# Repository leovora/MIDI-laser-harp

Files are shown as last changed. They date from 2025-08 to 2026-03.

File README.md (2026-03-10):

# MIDI Laser Harp






> **University Project** — Making Lab Course, A.Y. 2024/2025 <br>
> Alma Mater Studiorum — Università di Bologna <br>
> Author: [Leonardo Vorabbi](https://github.com/leovora)

---

This project was developed as part of the **Making Lab** course exam (Academic Year 2024/2025) at the **Master's Degree in Computer Science, University of Bologna**.

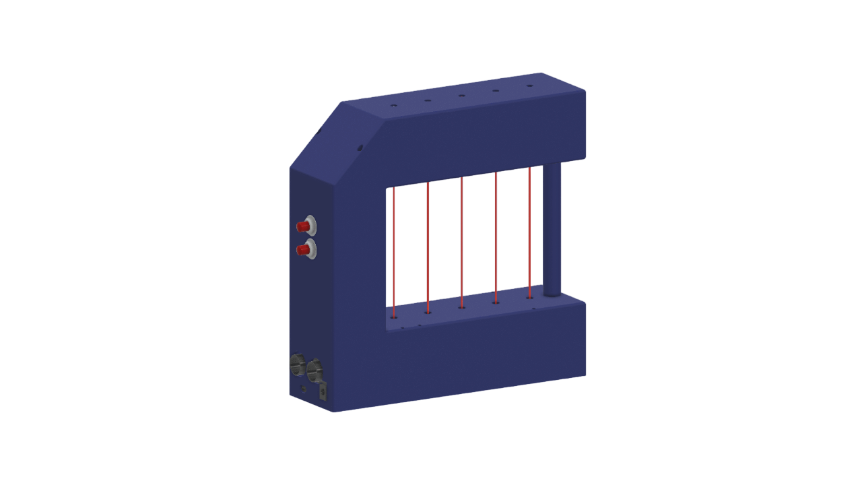
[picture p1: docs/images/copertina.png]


## Project Description
The goal of my project was to design and build a **laser harp MIDI controller**, capable of interacting with music software (such as Ableton, Logic, or other DAWs) through MIDI messages.

The system works by projecting laser beams onto LDR sensors: interrupting a beam is interpreted as triggering or releasing a note (Note On/Off).

In addition to the core functionality, the following features were integrated:
- **Feedback LEDs**, to provide visual feedback to the user;
- **Ultrasonic sensor**, for continuous control of MIDI parameters (e.g. effects or modulation);
- **Octave shift buttons**, to extend the musical range of the instrument;
- a **configuration software** able to send and receive *Control Change* messages for note remapping and device status monitoring.

## CAD Model
The physical structure of the instrument was designed in **Autodesk Fusion 360** and built using **FDM 3D printing**.

Exploded model

## Technologies Used
- **Arduino + MIDIUSB** for MIDI message handling
- **NewPing** for the ultrasonic sensor
- **Autodesk Fusion 360** for CAD modeling
- **Ultimaker Cura** and **Ultimaker 3** for 3D printing
- **Ableton Live** as the reference DAW for testing

## Repository Structure
- `src/` → Arduino code (for the device) and Python code (for the configuration software)
- `stl/` → 3D models in STL format
- `docs/` → images and additional documentation

## Author
Project developed by **Leonardo Vorabbi**  
University of Bologna – Master's Degree in Computer Science  
Making Lab, A.Y. 2024/2025

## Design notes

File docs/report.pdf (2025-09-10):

## Report progetto Laboratorio di Making Universit`a di Bologna

A.A. 2024-25

## MIDI Laser-Harp

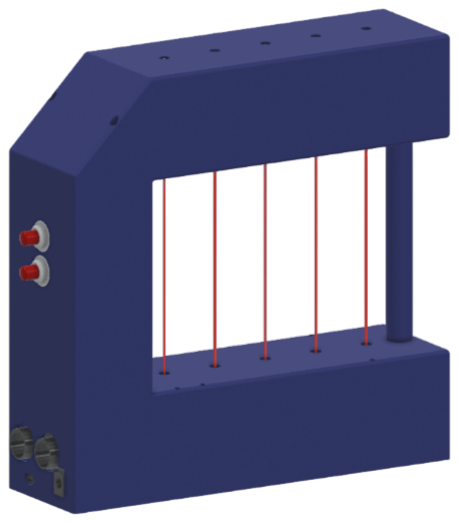
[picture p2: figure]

### Leonardo Vorabbi

0001186597

### Email

leonardo.vorabbi@studio.unibo.it

## Indice

1 Introduzione | 2
2 Stato dell’arte | 3
3 Materiali e componenti utilizzati | 5
4 Progettazione | 6
4.1.2 | Codice Arduino per calibrazione e lettura dei sensori . | 7
4.3.1 | Trasferimento del circuito dalla breadboard a stripboard 10
5 Conclusioni | 15
6 Appendice | 16

1

## 1 Introduzione

### 1.1 Contesto del progetto

Negli ultimi anni il campo degli strumenti musicali elettronici ha conosciuto una rapida evoluzione, grazie alla diffusione di controller MIDI sempre pi`u vari e innovativi. Accanto a tastiere, pad e superfici di controllo tradizionali, sono comparsi strumenti alternativi che sfruttano diverse tecnologie per offrire modalit`a di interazione pi`u intuitive ed espressive.

Tra i marchi pi`u innovativi nel settore dei controller MIDI spicca ROLI, che ha introdotto soluzioni capaci di ampliare notevolmente le possibilit`a espressive del musicista. Con la serie Seaboard, ROLI ha portato sul mercato superfici sensibili alla pressione e al movimento, basate sul protocollo MPE (MIDI Polyphonic Expression), che consentono di modulare parametri sonori in tempo reale con un approccio molto pi`u fluido rispetto alle tastiere tradizionali. A queste si affiancano dispositivi come l’Airwave, che sfruttano la visione artificiale per interpretare i gesti del performer e tradurli in controlli musicali, aprendo la strada a un’interazione pi`u naturale e gestuale con il suono.

In questo panorama si colloca il progetto MIDI Laser-Harp, che si ispira alle celebri arpe laser utilizzate in ambito performativo da artisti come Jean-Michel Jarre, ma con un approccio pi`u accessibile e compatto. L’obiettivo `e creare un dispositivo che permetta all’esecutore di interagire gestualmente con fasci di luce, traducendo l’interruzione dei laser in segnali MIDI compatibili con software musicali e sintetizzatori.

Il progetto si inserisce quindi nel filone della ricerca di nuove interfacce uomo–macchina per la musica elettronica, ponendo l’accento sull’aspetto performativo e sulla libert`a gestuale.

### 1.2 Controller e protocollo MIDI

Un controller musicale non produce suoni autonomamente, ma invia comandi a un generatore sonoro esterno, che pu`o essere un sintetizzatore hardware o un software di produzione musicale. Questi comandi sono trasmessi tramite il protocollo MIDI (Musical Instrument Digital Interface), uno standard introdotto negli anni ’80 che consente a strumenti e computer di comunicare tra loro. Il MIDI non trasporta il suono, ma una serie di istruzioni digitali, come “nota ON/nota OFF”, che vengono interpretate dal dispositivo ricevente per generare o modulare il suono. In questo modo, un controller come

2

l’arpa laser pu`o diventare un’interfaccia che permette al musicista di suonare virtualmente strumenti molto diversi tra loro e delegando la sintesi del suono al dispositivo/software ricevente.

### 1.3 Obiettivo del progetto

Obiettivo del progetto `e la realizzazione di un’arpa laser MIDI. L’intento `e sviluppare uno strumento musicale alternativo capace di trasformare l’interruzione di fasci laser in segnali MIDI standard, in modo da poter interagire facilmente con software di produzione musicale e sintetizzatori hardware. La progettazione include non solo l’elettronica di rilevamento e comunicazione, ma anche la creazione di un contenitore stampato in 3D che integri in maniera ordinata laser, sensori e scheda di controllo. L’obiettivo finale `e fornire un dispositivo completo che possa fungere da base per future estensioni.

## 2 Stato dell’arte

### 2.1 Prodotti esistenti

A seguito di una ricerca online, ho individuato un solo prodotto attualmente in vendita che possa essere definito a tutti gli effetti un’arpa laser: si tratta del modello proposto su laser-harp.com, commercializzato a 999 €. Questo strumento, tuttavia, si discosta molto dal progetto qui presentato: `e concepito principalmente come dispositivo scenografico, pensato per spettacoli e performance dal forte impatto visivo, ma con funzionalit`a musicali piuttosto limitate e un costo che lo rende poco accessibile.

In parallelo esistono altri controller MIDI alternativi basati su sensori di movimento o di prossimit`a. Tra questi, ad esempio, il Leap Motion e l’Airwave di ROLI (basati su sensori ottici capaci di rilevare con precisione i gesti delle mani nello spazio). E importante sottolineare per`o che questi dispositivi sono ` accomunati all’arpa laser soltanto dall’obiettivo di rendere l’interazione con il suono pi`u naturale e immediata rispetto a tastiere o controller tradizionali, offrendo tuttavia interfacce gestuali diverse.

### 2.2 Analisi progetti online

Online sono disponibili diversi progetti di arpe laser, come ad esempio https: //www.instructables.com/Laser-Harp-2/. La maggior parte di essi si basa su un unico laser di potenza relativamente elevata (> 50 mW), il cui fascio

3

viene deviato da uno specchio montato su un motore passo-passo che ruota ad alta velocit`a. In questo modo si ottiene l’illusione di avere pi`u raggi paralleli, corrispondenti a corde virtuali. Un LDR misura la luminosit`a e l’eventuale interruzione del fascio viene associata a una determinata nota, in base alla posizione del motore durante l’interruzione. Questo approccio, seppur scenografico, presenta diversi limiti: il costo del laser, la scarsa portabilit`a, il rischio per gli occhi dovuto all’uso di raggi potenti e la riduzione del controllo musicale a un semplice on/off per nota.

Il progetto sviluppato adotta invece una logica differente: utilizza pi`u laser indipendenti a bassa potenza ciascuno allineato con un proprio LDR dedicato. Questa soluzione risulta meno spettacolare dal punto di vista scenico, ma molto pi`u funzionale e sicura, perch´e permette la realizzazione di un frame stampato in 3D in cui possono essere integrati altri sensori e controlli aggiuntivi, rendendo il sistema pi`u versatile. Tra i limiti rimangono la necessit`a di un allineamento preciso tra laser e sensori e una resa visiva meno scenica rispetto alle soluzioni con fasci riflessi.

4

## 3 Materiali e componenti utilizzati

### 3.1 Tabella dei componenti elettronici

Categoria | Componente | Quantit`a | Note
Scheda di controllo | Arduino Leonardo (+ protoboard) | 1 | Compatibile con MIDI via USB grazie a AT-mega32u4
Laser | HiLetgo 5 mW 650 nm Red DOT Laser Mo-dule (KY-008) | 5 | Moduli laser 5 V, luce rossa, 650 nm
Sensori ottici | LDR | 5 | Per rilevare l’interru-zione del fascio laser
Resistenze | 220 Ω | 10 | 5 per le LDR, 5 per i LED
LED | LED 5 mm | 5 | Indicatori visivi per ogni “corda”
Sensori addizionali | Sensore a ultrasuoni | 1 | Per rilevare la distan-za delle mani
Pulsanti | Pulsanti standard | 2 | Per cambio ottava
PCB | Schede perforate | 2 | Per assemblaggio e saldatura
Cablaggio | Jumper | vari

Tabella 1: Componenti elettronici principali

5

### 3.2 Tabella dei componenti di supporto

Categoria | Componente | Quantit`a | Note
Assemblaggio | Viti M3 autofilettanti | varie | Per fissaggio delle par-ti stampate in PLA
Strumenti di supporto | “Terza mano” con pinze | 1 | Per facilitare le salda-ture
Materiali stampa 3D | Filamento PLA | variabile | Per la realizzazione del ”frame”
Stampante 3D | Ultimaker 3 | 1 | Stampa del ”frame”
Software CAD/CAM | Fusion 360, Ultimaker Cura | — | Modellazione e slicing per stampa 3D

Tabella 2: Componenti di supporto e strumenti

## 4 Progettazione

### 4.1 Prototipazione su breadboard

### 4.1.1 Schema del circuito preliminare

Per la fase di prototipazione `e stato realizzato un primo circuito di test su breadboard con lo scopo di verificare il corretto funzionamento del principio di base: l’interruzione di un fascio laser rilevata da un fotoresistore (LDR) viene tradotta in un segnale digitale visibile tramite l’accensione di un LED.

Nel prototipo sono stati utilizzati:

- Due moduli laser (650 nm, 5 mW), collegati direttamente all’alimentazione a 5V fornita da Arduino Leonardo.
- Due LDR, ognuno in partitore resistivo con una resistenza da 220 Ω. Il punto centrale del partitore veniva letto da un ingresso analogico di Arduino per rilevare la variazione di luminosit`a.
- Due LED da 5 mm, ciascuno con una resistenza da 220 Ω in serie, collegati alle uscite digitali di Arduino. I LED fungevano da indicatori visivi dello “stato della corda”: spenti quando il fascio era attivo e accesi quando il fascio veniva interrotto.

6

- Due pulsanti momentanei, inizialmente collegati agli ingressi digitali di Arduino. La loro funzione era ancora in fase di definizione, ma sarebbero poi stati utilizzati per il controllo dell’ottava tramite messaggi MIDI.
- Un sensore a ultrasuoni, aggiunto per future sperimentazioni: lo scopo era valutare la possibilit`a di utilizzarlo come ulteriore parametro di controllo MIDI (per esempio, modulare un effetto in base alla distanza della mano).

Il prototipo realizzato [figura 4] ha permesso di testare la sensibilit`a degli LDR rispetto ai moduli laser e di iniziare a scrivere il codice per la calibrazione degli LDR e la trasmissione dei vari segnali MIDI.

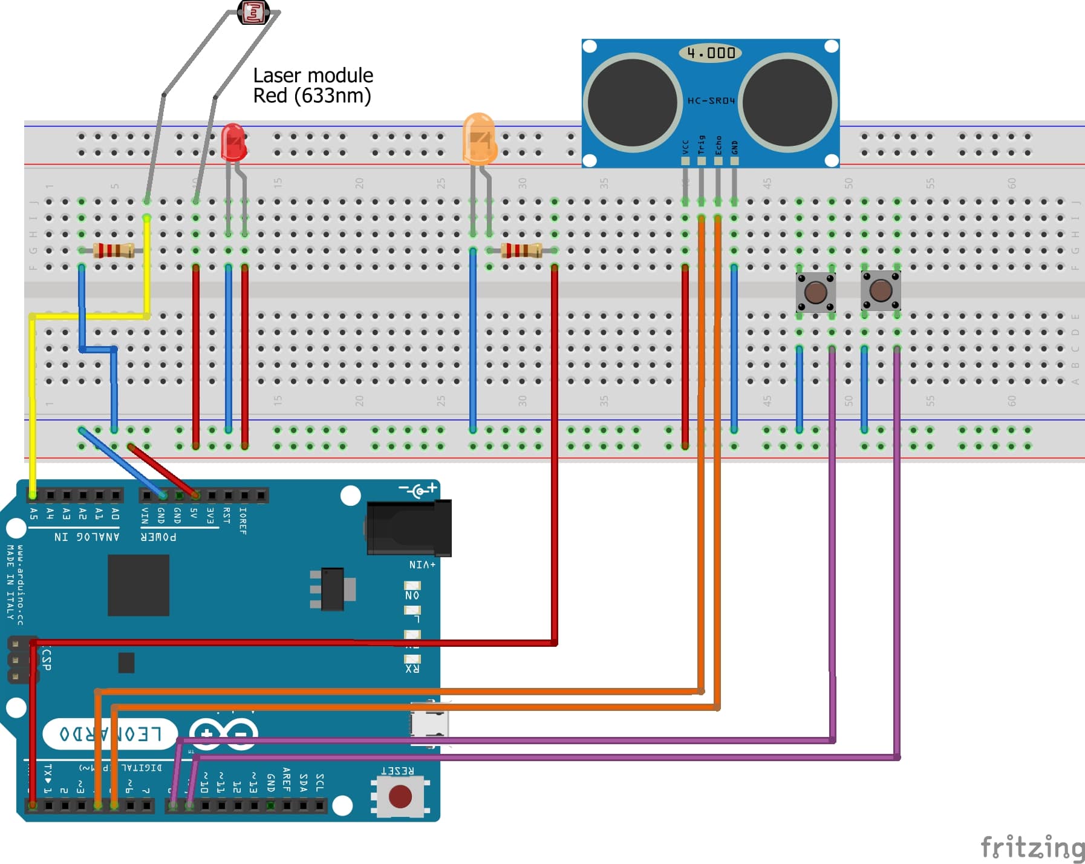
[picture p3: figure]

Figura 1: Schema circuito considerando un solo fascio laser

### 4.1.2 Codice Arduino per calibrazione e lettura dei sensori

Al fine di ridurre al minimo l’impatto della luce ambientale, variabile a seconda del contesto di utilizzo, sulla lettura dei sensori, `e stata implementata

7

una procedura di calibrazione automatica dei singoli LDR. Durante la fase di setup, ciascun sensore viene campionato per 100 letture consecutive mentre il relativo fascio laser `e attivo. La media di questi valori viene utilizzata per calcolare una soglia dinamica (threshold), leggermente inferiore alla luminosit`a rilevata in condizioni normali. In questo modo il sistema `e in grado di adattarsi alle variazioni di luce ambientale e ridurre gli errori di lettura. Nel ciclo principale, i valori analogici provenienti dagli LDR vengono confrontati con la soglia calcolata. Quando il valore scende al di sotto della soglia, significa che il fascio `e stato interrotto, e il sistema attiva la nota corrispondente, mentre quando il valore torna al di sopra della soglia, la nota viene spenta. Questo meccanismo consente di rilevare in tempo reale l’interruzione dei fasci laser e di associare ogni “corda” luminosa a una specifica nota MIDI. L’aggiunta di LED di feedback collegati a ciascun sensore permette inoltre di verificare visivamente l’attivazione e il rilascio delle note durante i test su breadboard.

Sebbene nel prototipo fossero gi`a presenti i due pulsanti e il sensore a ultrasuoni, in questa fase preliminare il codice si `e concentrato esclusivamente sulla calibrazione e sulla lettura degli LDR, rimandando l’implementazione delle funzionalit`a avanzate alla fase successiva.

Il codice completo `e disponibile al link github del progetto oppure cliccando qui.

### 4.2 Comunicazione MIDI

### 4.2.1 Codice Arduino per comunicazione MIDI

Per permettere all’arpa laser di interagire con software musicali e strumenti esterni, `e stata implementata la comunicazione MIDI tramite la libreria MIDIUSB di Arduino. Il MIDI (Musical Instrument Digital Interface) `e un protocollo digitale standardizzato che non trasmette audio, ma messaggi di controllo: istruzioni come “Nota On”, “Nota Off”, “Control Change” o “Program Change” che descrivono come uno strumento deve generare o modificare un suono.

Ogni messaggio MIDI tradizionale `e composto da tre byte:

1. Status byte: indica il tipo di messaggio e il canale MIDI (1–16).
2. Data byte 1: numero della nota o ID del controller.
3. Data byte 2: velocit`a della nota o valore del controller (0–127).

8

Quando si utilizza la libreria MIDIUSB, questi tre byte vengono incapsulati in un pacchetto USB-MIDI a quattro byte (midiEventPacket t), dove il primo byte (cin) indica al computer il tipo di messaggio USB-MIDI, mentre i successivi tre byte corrispondono ai classici messaggi MIDI.

La gestione avviene secondo due funzioni principali:

- Nota ON: quando il valore letto dall’LDR scende sotto la soglia di calibrazione, Arduino invia un messaggio Note On contenente il numero della nota corrispondente e la velocit`a massima (127). Contestualmente, viene inviato anche un messaggio di Control Change: questo non influisce sulla riproduzione musicale, ma viene utilizzato dal programma di configurazione dello strumento per aggiornare la grafica e monitorare lo stato dei sensori.
- Nota OFF: quando il valore torna sopra la soglia, Arduino invia il messaggio Note Off per la stessa nota, indicando cos`ı al software MIDI che il tasto virtuale `e stato rilasciato. Anche in questo caso viene inviato un Control Change per aggiornare il monitoraggio visivo nell’interfaccia di configurazione.

L’elenco delle note assegnate agli LDR `e gestito tramite un array (noteBase[]), che definisce la nota di riferimento per ciascun sensore. A questa nota di base pu`o essere applicato uno shift di ottava (positivo o negativo), determinato dai pulsanti presenti sul prototipo.

Sensore Nota MIDI Nota musicale
LDR1 | 60 | Do4
LDR2 | 62 | Re4
LDR3 | 64 | Mi4
LDR4 | 65 | Fa4
LDR5 | 67 | Sol4

Tabella 3: Note associate a ciascun LDR (Scala Do maggiore - prime 5 note)

Oltre ai messaggi di nota, il codice `e predisposto anche per l’invio di Control Change (CC), che permettono di mappare altri parametri musicali, come ad esempio il controllo di effetti.

Il codice completo `e disponibile al link github del progetto oppure cliccando qui.

9

### 4.2.2 Test con Ableton

Per testare il funzionamento musicale del prototipo, `e stato utilizzato Ableton Live, una delle principali Digital Audio Workstation (DAW) che permette di registrare, riprodurre e modificare musica digitale, gestendo tracce audio e MIDI.

I primi test si sono rivelati relativamente semplici: `e bastato collegare il prototipo al PC tramite USB, aprire Ableton, creare una traccia MIDI, selezionare uno strumento virtuale e attivarlo. Una volta fatto ci`o, ogni interruzione di fascio laser corrispondeva all’invio di un messaggio Note On/Off, e il suono selezionato veniva riprodotto in tempo reale.

Per testare il controllo aggiuntivo fornito dal sensore a ultrasuoni, `e stato sufficiente entrare in modalit`a MIDI Map di Ableton e selezionare il parametro desiderato da controllare (ad esempio il volume o un effetto di riverbero) associandolo al messaggio di Control Change inviato dal sensore. In questo modo il movimento della mano davanti al sensore modulava in tempo reale il parametro selezionato.

### 4.3 Assemblaggio e saldatura

### 4.3.1 Trasferimento del circuito dalla breadboard a stripboard

Dopo la fase di prototipazione su breadboard, `e stato necessario realizzare un circuito pi`u stabile e compatto, trasferendo il tutto su stripboard.

In particolare, sono stati saldati sulla stripboard il circuito dei fotoresistori e i relativi LED con resistenze, ovvero la sezione del circuito dedicata alla rilevazione delle interruzioni dei fasci laser e al feedback visivo, garantendo una maggiore robustezza.

Successivamente `e stato saldato anche il sensore a ultrasuoni direttamente sulla protoboard di Arduino, insieme ad alcuni jumper necessari a facilitare i collegamenti con il resto del sistema.

Gli altri componenti (moduli laser, pulsanti, ecc.) non sono stati integrati direttamente sulla stripboard, ma fissati in altri modi sfruttando la struttura stampata in 3D.

Per completare l’intero circuito `e stato inoltre necessario saldare numerosi cavi, al fine di unire tra loro le varie parti distribuite nel dispositivo.

10

### 4.4 Progettazione e modellazione 3D

### 4.4.1 Preparazione e misurazione

La progettazione della struttura dell’arpa laser `e partita da un abbozzo a matita, utile per definire la disposizione generale dei componenti [figura 5]. Nello schema iniziale, l’Arduino Leonardo con il sensore a ultrasuoni era collocato in basso a sinistra, mentre i moduli laser occupavano la parte centrale e destra della base. La colonna verticale a sinistra era pensata come passaggio per il cablaggio verso la parte superiore, oltre che come alloggiamento dei pulsanti per il cambio di ottava. Nella parte superiore trovavano posto gli LDR e i LED: i primi rivolti verso il basso, in modo da allinearsi con i fasci laser, e i secondi orientati verso l’alto, per essere ben visibili all’utente.

Dopo aver definito questa disposizione, `e stato necessario misurare accuratamente tutti i componenti elettronici per poterli riprodurre fedelmente in CAD e garantire un corretto alloggiamento.

### 4.4.2 Disegno CAD e stampa FDM

La modellazione `e stata svolta con Autodesk Fusion 360 e ha rappresentato una delle fasi pi`u impegnative del progetto, trattandosi della mia prima esperienza in modellazione 3D. E stato necessario non solo progettare i singoli ` pezzi, ma anche pensare a come renderli assemblabili e solidi, introducendo alloggiamenti e fori per le viti di fissaggio. Tutti i file STL prodotti sono disponibili nel repository GitHub: github.com/leovora/MIDI-laser-harp.

11

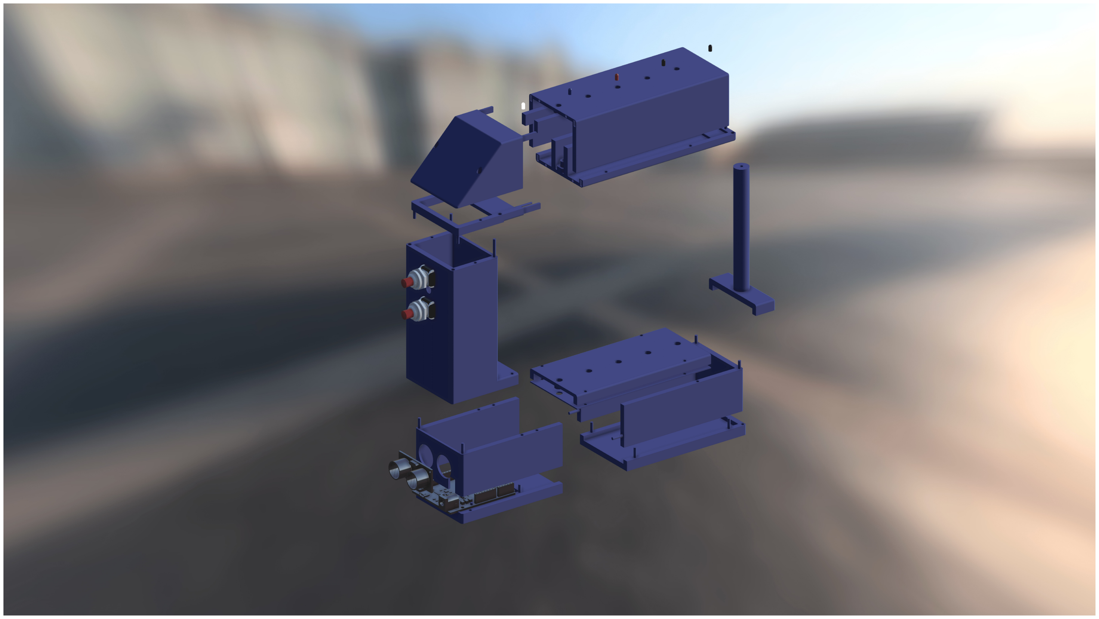
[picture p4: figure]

Figura 2: Mockup esploso con risalto sui singoli pezzi

La stampa `e stata effettuata con tecnologia FDM utilizzando Ultimaker Cura per il slicing e una Ultimaker 3 (ricevuta in prestito per un periodo limitato) per la realizzazione fisica dei componenti. Il processo `e stato di natura fortemente iterativa: modellavo un pezzo, lo stampavo, e durante la stampa lavoravo al modello successivo. In diversi casi `e stato necessario ristampare alcune parti dopo aver corretto errori di progettazione o piccole imprecisioni.

### 4.5 Assemblaggio finale

### 4.5.1 Difficolt`a riscontrate

La fase di assemblaggio `e stata senza dubbio quella in cui sono emerse le maggiori difficolt`a, poich´e solo mettendo insieme tutte le parti stampate e i componenti elettronici `e stato possibile verificare concretamente eventuali errori progettuali.

Il primo problema rilevante `e stato legato al cablaggio. Inizialmente avevo saldato ad ogni componente i propri collegamenti di alimentazione (5 V e GND), arrivando cos`ı a dover connettere oltre 30 cavi direttamente ad Arduino. Oltre alla complessit`a del cablaggio, il vero ostacolo era rappresentato dal fatto che tutti questi fili faticavano a passare all’interno della colonna sinistra. Per risolvere il problema ho dovuto tagliare e saldare molti cavi tra

12

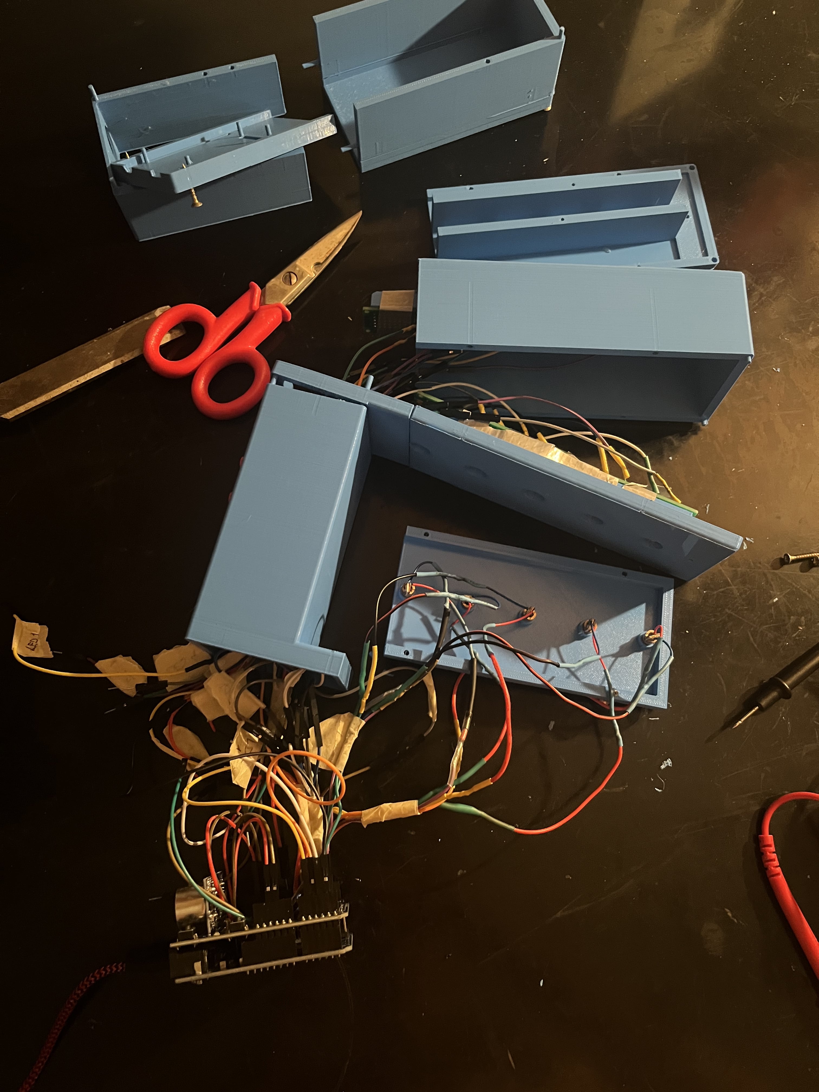
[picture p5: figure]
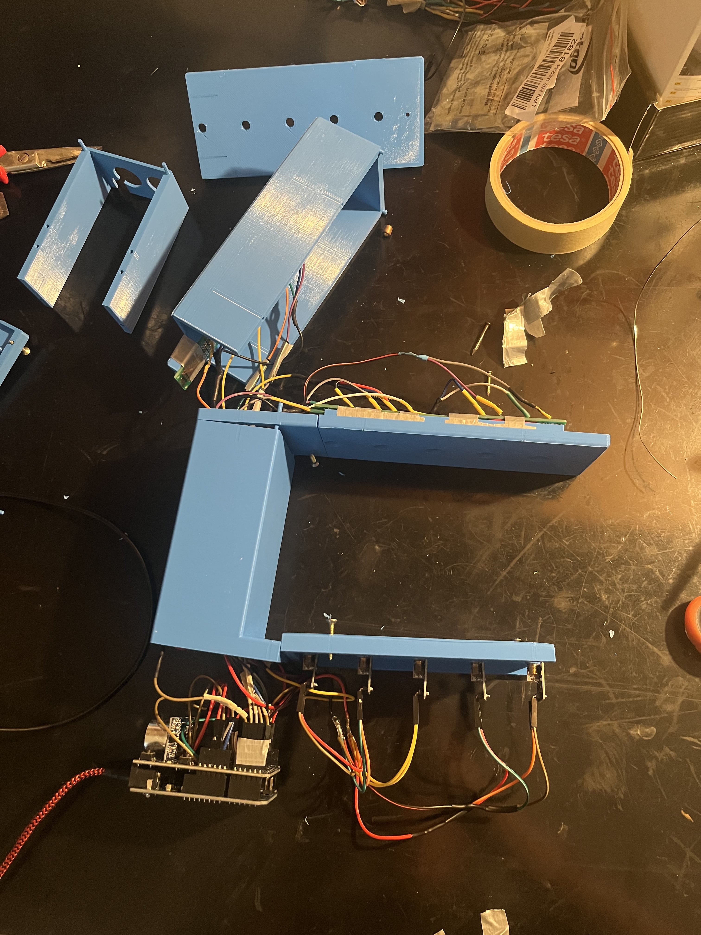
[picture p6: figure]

(a) Prima delle correzioni | (b) Dopo le correzioni

Figura 3: Confronto prima e dopo correzioni assemblaggio

loro, riducendo notevolmente il numero di jumper e rendendo il circuito pi`u gestibile.

Un’altra criticit`a `e stata l’allineamento dei laser con gli LDR. Nonostante nel modello CAD i fori fossero perfettamente allineati, i moduli laser avevano troppo gioco all’interno delle sedi, causando disallineamenti. Ho quindi ristampato sia gli alloggi degli LDR, realizzando fori pi`u larghi e conici per catturare il fascio anche in caso di leggera deviazione, sia la base dei laser, ridisegnata con fori calibrati sulle dimensioni reali dei moduli, per impedirne ogni movimento.

Nonostante queste correzioni, il problema non era del tutto risolto: i moduli laser stessi si sono rivelati poco affidabili. Ogni fascio aveva caratteristiche diverse (pi`u largo, pi`u stretto, inclinato) e, dopo pochi minuti di utilizzo, tendevano a surriscaldarsi, con conseguente calo di intensit`a luminosa. La soluzione definitiva `e stata sostituirli con moduli di qualit`a superiore.

Superati questi ostacoli principali, il resto dell’assemblaggio `e proceduto come previsto, consentendo di ottenere una struttura solida e un circuito ordinato e funzionale.

13

### 4.6 Implementazione software di configurazione

Poich´e l’arpa laser dispone di soli 5 fasci luminosi, ho ritenuto importante sviluppare un software di configurazione che ne aumentasse la versatilit`a. L’applicazione `e stata realizzata in Python, utilizzando la libreria Tkinter per l’interfaccia grafica e Mido per la gestione dei messaggi MIDI.

Il software svolge tre funzioni principali:

- Configurazione manuale: l’utente pu`o assegnare liberamente una nota MIDI a ciascun laser.
- Preset di scala: `e possibile selezionare una tonica e una scala musicale predefinita (maggiore, minore, pentatonica, blues, ecc.), che vengono applicate automaticamente ai 5 fasci.
- Monitoraggio in tempo reale: l’interfaccia mostra lo stato del dispositivo, come note attive, ottava selezionata e distanza rilevata dal sensore a ultrasuoni.

La comunicazione tra il software di configurazione e Arduino si basa principalmente sull’uso di messaggi MIDI di tipo Control Change (CC).

Il flusso dei dati avviene in due direzioni:

- Dal software verso Arduino: quando l’utente assegna manualmente una nota a un laser o seleziona una scala predefinita, il programma invia un messaggio MIDI Control Change con numero di controllo compreso tra 20 e 24. Il valore del messaggio corrisponde al numero della nota MIDI da associare al relativo fascio. Arduino riceve il CC, aggiorna l’array noteBase[] e utilizza quel valore come nota di riferimento per gli eventi Note On/Off successivi.
- Da Arduino verso il software: la scheda, durante il normale funzionamento, invia a sua volta messaggi MIDI utili al monitoraggio dello stato:

– CC 30–34: indicano l’accensione o lo spegnimento dei LED associati ai laser (nota attiva o rilasciata).

– CC 40: comunica l’ottava corrente.

– CC 91: trasmette il valore di distanza rilevato dal sensore a ultrasuoni, gi`a scalato nell’intervallo 0–127.

14

Grazie a questo scambio, il software pu`o non solo configurare le note ma anche visualizzare in tempo reale l’attivit`a dello strumento (stato dei fasci, ottava, sensore).

## 5 Conclusioni

### 5.1 Risultati ottenuti

Il progetto ha portato alla realizzazione funzionante di un controller MIDI a forma di arpa laser, capace di interagire con software musicali e di essere configurato tramite un’apposita interfaccia software. L’hardware, composto da Arduino, sensori LDR, moduli laser e un sensore a ultrasuoni, `e stato integrato in una struttura stampata in 3D, superando le difficolt`a di assemblaggio e cablaggio. Il risultato `e uno strumento che traduce i gesti dell’utente in segnali MIDI standard, permettendo di suonare note e controllare parametri in tempo reale. In questo modo `e stato raggiunto l’obiettivo iniziale: un dispositivo originale, funzionale e in grado di unire elettronica, programmazione e musica in un’unica esperienza interattiva.

### 5.2 Possibili miglioramenti

Nonostante il funzionamento soddisfacente, il progetto presenta margini di evoluzione. Tra i miglioramenti futuri possibili si evidenziano:

- Aumento del numero di laser: aggiungendo altri moduli laser si potrebbe ottenere un’intera ottava completa, aumentando la gamma musicale disponibile e la flessibilit`a dell’arpa.
- Miglioramento della struttura: ottimizzando la base e gli alloggi dei laser si potrebbe facilitare l’allineamento, rendendo la proiezione dei fasci pi`u precisa e stabile. E possibile pensare anche a soluzioni ` dinamiche che correggano automaticamente la posizione dei laser in tempo reale.
- Software di configurazione avanzato: trasformare il programma di configurazione in un plugin DAW permetterebbe di gestire note e parametri direttamente all’interno del software musicale, senza passare da un’applicazione esterna.
- Estensione delle funzionalit`a MIDI: aggiungere mapping configurabili, preset, salvataggio delle impostazioni e controllo di ulteriori pa-

15 rametri musicali per rendere il dispositivo pi`u versatile e integrabile in contesti live o di produzione.

## 6 Appendice

### 6.1 Codici sorgente

### 6.1.1 Codice Arduino

#include "MIDIUSB.h"

#include <NewPing.h>

// ===== Pin LDR e LED =====
#define NUM_NOTE 5

const int LDRpin[NUM_NOTE] = {A5, A4, A3, A2, A1}; const int LEDpin[NUM_NOTE] = {2, 3, 4, 5, 6};

// ===== Sensore ultrasuoni =====
#define TRIG_PIN 10

#define ECHO_PIN 11

#define MAX_DISTANCE 15

NewPing sonar(TRIG_PIN, ECHO_PIN, MAX_DISTANCE);

// ===== Pulsanti Ottava =====
#define BTN_DOWN 8

#define BTN_UP 9

// ===== MIDI =====
byte noteBase[NUM_NOTE] = {60, 62, 64, 65, 67};
bool notaInviata[NUM_NOTE] = {false, false, false, false, false};

int THRESHOLD[NUM_NOTE];
int ottavaCorrente = 0;

// ===== Ultrasuono =====
int distanza = 0;
unsigned long lastPing = 0;

16 const unsigned long pingInterval = 50;

// ===== Antirimbalzo pulsanti ===== unsigned long lastDebounce = 0;
const unsigned long debounceDelay = 200;

void setup() {
Serial.begin(9600);

for (int i = 0; i < NUM_NOTE; i++) { pinMode(LDRpin[i], INPUT); pinMode(LEDpin[i], OUTPUT); THRESHOLD[i] = calibraSingoloLaser(i); }

pinMode(BTN_DOWN, INPUT_PULLUP); pinMode(BTN_UP, INPUT_PULLUP); }

void loop() {
// === Lettura LDR ===
for (int i = 0; i < NUM_NOTE; i++) {
int val = analogRead(LDRpin[i]);

if (val < THRESHOLD[i] && !notaInviata[i]) { inviaNotaOn(noteBase[i] + (ottavaCorrente * 12), i); notaInviata[i] = true;
digitalWrite(LEDpin[i], HIGH);
}
else if (val >= THRESHOLD[i] && notaInviata[i]) { inviaNotaOff(noteBase[i] + (ottavaCorrente * 12), i); notaInviata[i] = false;
digitalWrite(LEDpin[i], LOW);
}
}

// === Ultrasuono con intervallo ===
if (millis() - lastPing >= pingInterval) { gestisciUltrasuono();
lastPing = millis();
}

17

// === Gestione Pulsanti === gestisciOttava();

// === Controllo messaggi da interfaccia === midiEventPacket_t rx;
do {
rx = MidiUSB.read();
if (rx.header != 0) {
if ((rx.byte1 & 0xF0) == 0xB0) { // CC message byte controller = rx.byte2;
byte value = rx.byte3;
if (controller >= 20 && controller <= 24) { int index = controller - 20; // LDR 0..4 noteBase[index] = value;
Serial.print("Aggiornata nota LDR "); Serial.print(index);
Serial.print(" -> ");
Serial.println(value);
}
}
}
} while (rx.header != 0);

delay(2);
}

// ===== Calibrazione LDR ===== int calibraSingoloLaser(int index) { long somma = 0;
const int letture = 100;

Serial.print("Calibrazione LDR "); Serial.print(index);
Serial.println(" (laser attivo)...");

for (int i = 0; i < letture; i++) { somma += analogRead(LDRpin[index]); delay(5);
}

18 int media = somma / letture;
int threshold = max(media - 100, 10);

Serial.print("Threshold LDR "); Serial.print(index);
Serial.print(": ");
Serial.println(threshold);

return threshold;
}

// ===== MIDI =====
void inviaControlChange(byte controller, byte value) { midiEventPacket_t cc = {0x0B, 0xB0, controller, value}; MidiUSB.sendMIDI(cc);
MidiUSB.flush();
}

void inviaNotaOn(byte nota, int index) { midiEventPacket_t noteOn = {0x09, 0x90, nota, 127}; MidiUSB.sendMIDI(noteOn);

inviaControlChange(30 + index, 127); // comunicazione ON con python

MidiUSB.flush();
Serial.print("Nota ON: "); Serial.print(nota);
Serial.print(" (index ");
Serial.print(index);
Serial.println(")");
}

void inviaNotaOff(byte nota, int index) { midiEventPacket_t noteOff = {0x08, 0x80, nota, 127}; MidiUSB.sendMIDI(noteOff);

inviaControlChange(30 + index, 0); // comunicazione OFF con python

MidiUSB.flush();

19

Serial.print("Nota OFF: "); Serial.print(nota);
Serial.print(" (index ");
Serial.print(index);
Serial.println(")");
}

void inviaOttava(int ottava) {
int val = 64 + ottava; // ottava = -3..+4 val = 61..68 inviaControlChange(40, val);
}

// ===== Gestione Pulsanti Ottava ===== void gestisciOttava() {
unsigned long now = millis();

if (now - lastDebounce > debounceDelay) {
if (digitalRead(BTN_UP) == LOW) { ottavaCorrente = min(4, ottavaCorrente + 1); Serial.print("Ottava aumentata a: "); Serial.println(ottavaCorrente); inviaControlChange(31, ottavaCorrente + 64); // shift (+64 per evitare valori negativi) inviaOttava(ottavaCorrente);
lastDebounce = now;
}

if (digitalRead(BTN_DOWN) == LOW) { ottavaCorrente = max(-3, ottavaCorrente - 1); Serial.print("Ottava diminuita a: "); Serial.println(ottavaCorrente); inviaControlChange(31, ottavaCorrente + 64); inviaOttava(ottavaCorrente);
lastDebounce = now;
}
}
}

// ===== Gestione ultrasuoni con NewPing ===== void gestisciUltrasuono() {
distanza = sonar.ping_cm();

20 if (distanza == 0) distanza = MAX_DISTANCE; // valore massimo se nessuna risposta

int valoreMIDI = map(distanza, 2, MAX_DISTANCE, 127, 0); valoreMIDI = constrain(valoreMIDI, 0, 127);

inviaControlChange(91, valoreMIDI);
}

### 6.1.2 Codice software di configurazione

import tkinter as tk
from tkinter import ttk
import mido

# === Setup MIDI ===

print("Porte MIDI disponibili:") print(mido.get_output_names())

MIDI_PORT_NAME = "Arduino Leonardo" outport = mido.open_output(MIDI_PORT_NAME) inport = mido.open_input(MIDI_PORT_NAME)

# === Costanti ===

NOTES = {
"Do (C)": 60, "Do# (C#)": 61, "Re (D)": 62, "Re# (D#)": 63, "Mi (E)": 64, "Fa (F)": 65, "Fa# (F#)": 66, "Sol (G)": 67, "Sol# (G#)": 68, "La (A)": 69, "La# (A#)": 70, "Si (B)": 71,
"Do (C) 2": 72, "Do# (C#) 2": 73, "Re (D) 2": 74, "Re# (D#) 2": 75,
"Mi (E) 2": 76, "Fa (F) 2": 77, "Fa# (F#) 2": 78, "Sol (G) 2": 79,
"Sol# (G#) 2": 80, "La (A) 2": 81, "La# (A#) 2": 82, "Si
(B) 2": 83
}

FIRST_OCTAVE = [ "Do (C)", "Do# (C#)", "Re (D)", "Re# (D#)", "Mi (E)", "Fa (F)", "Fa# (F#)", "Sol (G)",

21

"Sol# (G#)", "La (A)", "La# (A#)", "Si (B)"]

SCALES = {
"Maggiore (prime 5)": [0, 2, 4, 5, 7], "Minore (prime 5)": [0, 2, 3, 5, 7], "Maggiore Pentatonica": [0, 2, 4, 7, 9], "Minore Pentatonica": [0, 3, 5, 7, 10], "Blues": [0, 3, 5, 6, 7],
"Diatonica sospesa (Sus4)": [0, 2, 5, 7, 9], "Orientale": [0, 1, 4, 5, 7],
"Maggior armonica (prime 5)": [0, 2, 4, 7, 11], "Minore armonica (prime 5)": [0, 2, 3, 7, 10],
}

DEFAULT_COMBO_NOTES = ["Do (C)", "Re (D)", "Mi (E)", "Fa (F)", "Sol (G)"]

# === Funzioni utilitarie ===

def mostra_avviso(msg, widget=None, durata=1500): ’’’
Mostra popup dopo aver modificato le note :param msg: messaggio da visualizzare
:param widget:
:param durata: durata del popup
’’’
popup = tk.Toplevel()
popup.overrideredirect(True)
label = tk.Label(popup, text=msg, padx=10, pady=5, anchor="center")
label.pack()
popup.update_idletasks()
w, h = popup.winfo_width(), popup.winfo_height()

if widget:
x = widget.winfo_rootx() + widget.winfo_width()//2 -w//2
y = widget.winfo_rooty() + widget.winfo_height() + 5 else:
x = popup.winfo_screenwidth()//2 - w//2
y = popup.winfo_screenheight()//2 - h//2 popup.geometry(f"{w}x{h}+{x}+{y}")

22 popup.after(durata, popup.destroy)

# === GUI setup ===

root = tk.Tk()
root.title("Configurazione Arpa Laser MIDI") combos = []

def invia_config(mostra_popup=True):
’’’
Invia la nuova configurazione dell’arpa
:param mostra_popup: flag per mostrare o no il popup ’’’
for i, combo in enumerate(combos):
nota_val = NOTES[combo.get()] outport.send(mido.Message("control_change", control=20+i, value=nota_val))
print(f"Inviato LDR {i+1}: {combo.get()} ({nota_val})") if mostra_popup:
mostra_avviso("Note applicate", widget=btn_invia)

def imposta_scala():
’’’
Imposta la scala corrente in base ai valori nelle combobox ’’’
tonica, scala_nome = root_note_combo.get(), scale_combo.get()
if tonica not in NOTES or scala_nome not in SCALES: return

tonica_val = NOTES[tonica]
intervalli = SCALES[scala_nome] scale_notes = []

for semitoni in intervalli:
midi_val = tonica_val + semitoni
nome = next((k for k, v in NOTES.items() if v == midi_val), list(NOTES.keys())[0]) scale_notes.append(nome)

for i in range(5):
combos[i].set(scale_notes[i])

23 invia_config(mostra_popup=False) mostra_avviso("Scala applicata", widget=btn_scala)

# === Layout ===

# Colonna sinistra: configurazione manuale

label_left = ttk.Label(root, text="Configurazione manuale", font=("Roboto", 15))
frame_left = ttk.LabelFrame(root, labelwidget=label_left, padding=10)
frame_left.grid(row=0, column=0, padx=10, pady=10, sticky="nsew")

for i in range(5):
ttk.Label(frame_left, text=f"Laser {i+1}").grid(row=i, column=0, padx=5, pady=5, sticky="w")
combo = ttk.Combobox(frame_left, values=FIRST_OCTAVE, state="readonly")
combo.set(DEFAULT_COMBO_NOTES[i])
combo.grid(row=i, column=1, padx=5, pady=5) combos.append(combo)

btn_invia = ttk.Button(frame_left, text="Applica note", command=invia_config)
btn_invia.grid(row=6, column=0, columnspan=2, pady=10)

# Colonna destra: preset di scala

label_right = ttk.Label(root, text="Preset", font=("Roboto", 15))
frame_right = ttk.LabelFrame(root, labelwidget=label_right, padding=10)
frame_right.grid(row=0, column=1, padx=10, pady=10, sticky="nsew")

ttk.Label(frame_right, text="Tonica:").grid(row=0, column=0, sticky="w", padx=5, pady=5)
root_note_combo = ttk.Combobox(frame_right, values=FIRST_OCTAVE, state="readonly") root_note_combo.set("Do (C)") root_note_combo.grid(row=0, column=1, padx=5, pady=5)

24 ttk.Label(frame_right, text="Scala:").grid(row=1, column=0, sticky="w", padx=5, pady=5)
scale_combo = ttk.Combobox(frame_right, values=list(SCALES.keys()), state="readonly") scale_combo.set("Maggiore (prime 5)") scale_combo.grid(row=1, column=1, padx=5, pady=5)

btn_scala = ttk.Button(frame_right, text="Applica Scala", command=imposta_scala)
btn_scala.grid(row=2, column=0, columnspan=2, pady=10)

# === Frame stato ===

status_label = ttk.Label(root, text="Stato arpa", font=("Roboto", 15))
status_frame = ttk.LabelFrame(root, labelwidget=status_label, padding=10)
status_frame.grid(row=1, column=0, columnspan=2, padx=10, pady=10, sticky="nsew")

# --- LED ---

canvas_width, canvas_height = 300, 80
led_frame = ttk.Frame(status_frame) led_frame.grid(row=0, column=0, padx=5, pady=5) ttk.Label(led_frame, text="LED").pack(pady=(0,5)) led_canvas = tk.Canvas(led_frame, width=canvas_width, height=canvas_height)
led_canvas.pack()

led_radius = min(canvas_height // 3, 20)
spacing = canvas_width // 6
led_widgets =
[led_canvas.create_oval(spacing*(i+1)-led_radius, canvas_height//2-led_radius, spacing*(i+1)+led_radius,
canvas_height//2+led_radius, fill="gray", outline="") for
i in range(5)]

def aggiorna_led(index, acceso=True): ’’’

25

Aggiorna il colore del cerchio per indicare l’accensione o lo spegnimento del corrispettivo led
:param index: indice del led/cerchio
:param acceso: indica se led acceso o spento
’’’
if 0 <= index < len(led_widgets): led_canvas.itemconfig(led_widgets[index], fill="green" if acceso else "gray")

# --- Ottava ---

ottava_frame = ttk.Frame(status_frame) ottava_frame.grid(row=0, column=1, padx=5, pady=5) ttk.Label(ottava_frame, text="Ottava").pack(pady=(0,5)) ottava_label = tk.Label(ottava_frame, text="0", font=("Arial", 18, "bold"))
ottava_label.pack()
def aggiorna_ottava(val):
’’’
Aggiorna la label dell’ottava con il valore ricevuto :param val: valore da inserire
’’’
ottava_label.config(text=f"{val}")

# --- Ultrasuoni ---

ultra_frame = ttk.Frame(status_frame) ultra_frame.grid(row=0, column=2, padx=5, pady=5) ttk.Label(ultra_frame, text="Sensore").pack(pady=(0,5)) ultra_canvas = tk.Canvas(ultra_frame, width=60, height=canvas_height)
ultra_canvas.pack()
ultra_bar = ultra_canvas.create_rectangle(10, canvas_height, 50, canvas_height, fill="blue")
def aggiorna_ultrasuoni(distanza, max_dist=100):
’’’
Aggiorna il rettangolo per indicare il nuovo valore del sensore a ultrasuoni
:param distanza: distanza ricevuta
:param max_dist: distanza massima
’’’
altezza = max(10, min(canvas_height-10, canvas_height-10-(distanza/max_dist)*(canvas_height-20)))

26 ultra_canvas.coords(ultra_bar, 10, altezza, 50, canvas_height-10)

# Centra frame interni

for i in range(3): status_frame.grid_columnconfigure(i, weight=1)
led_frame.grid(sticky="n"); ottava_frame.grid(sticky="n"); ultra_frame.grid(sticky="n")

# === Lettura MIDI ===

def leggi_midi():
’’’
Legge i messaggi midi ricevuti da arduino ’’’
for msg in inport.iter_pending():
if msg.type == ’note_on’:
print(f"Nota ON ricevuta: {msg.note}") elif msg.type == ’note_off’:
print(f"Nota OFF ricevuta: {msg.note}") elif msg.type == ’control_change’:
if 30 <= msg.control <= 34: aggiorna_led(msg.control-30, msg.value>0) elif msg.control == 40:
aggiorna_ottava(msg.value-64)
elif msg.control == 91:
aggiorna_ultrasuoni(int((127-msg.value)*100/127)) else:
print(f"CC sconosciuto: {msg.control} value={msg.value}")
root.after(50, leggi_midi)

leggi_midi()
root.mainloop()

27

### 6.2 Immagini

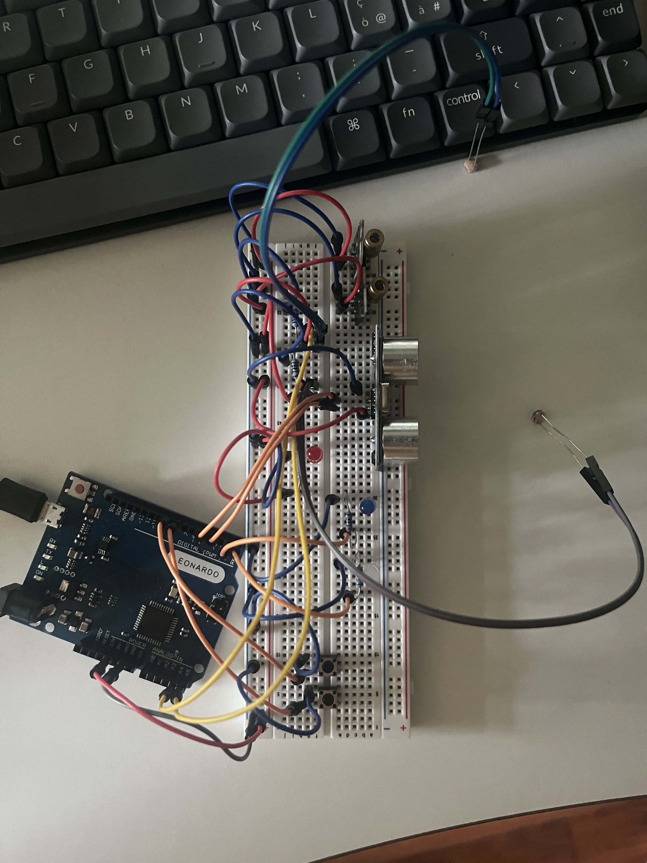
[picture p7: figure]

Figura 4: Primo prototipo su breadboard

28

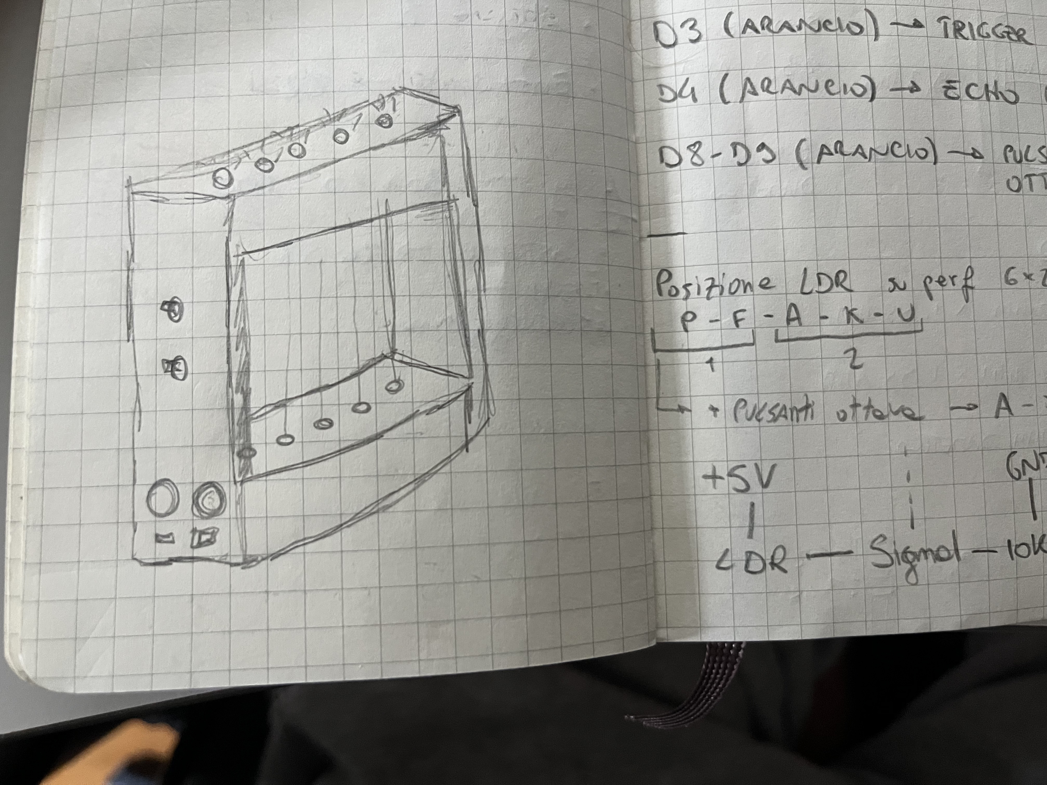
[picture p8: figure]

Figura 5: Primo schizzo dell’arpa laser

29

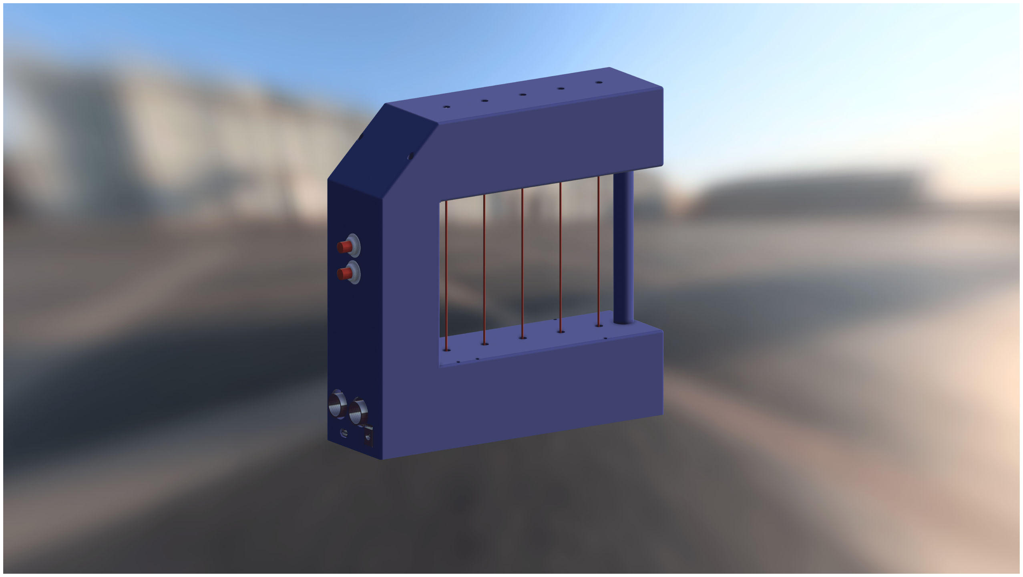
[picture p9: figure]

Figura 6: Mockup dell’arpa completata

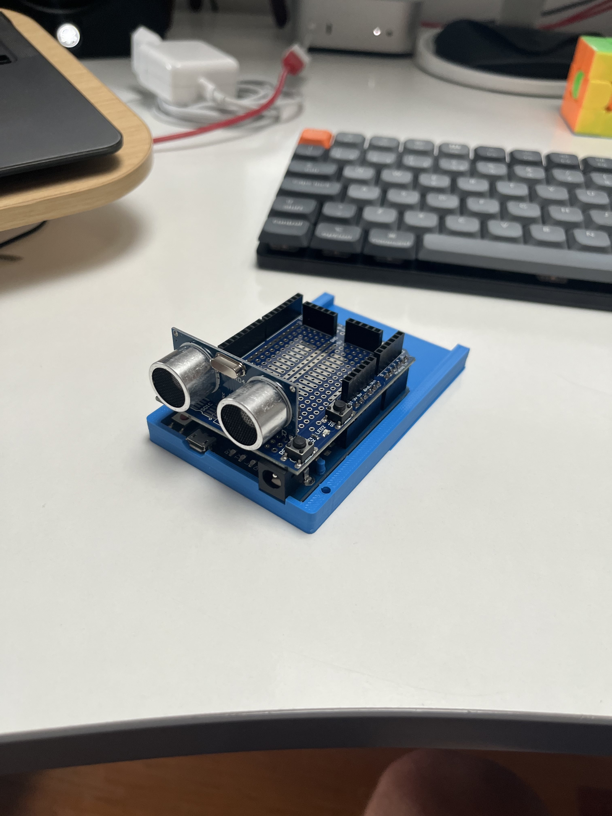
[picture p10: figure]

Figura 7: Primo pezzo stampato - contenitore arduino

30

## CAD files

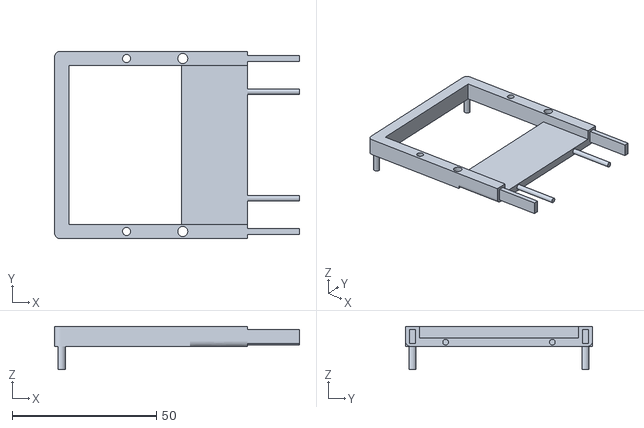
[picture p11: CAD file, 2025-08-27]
stl/sopra sinistra.stl
85.0 x 65.0 x 15.0

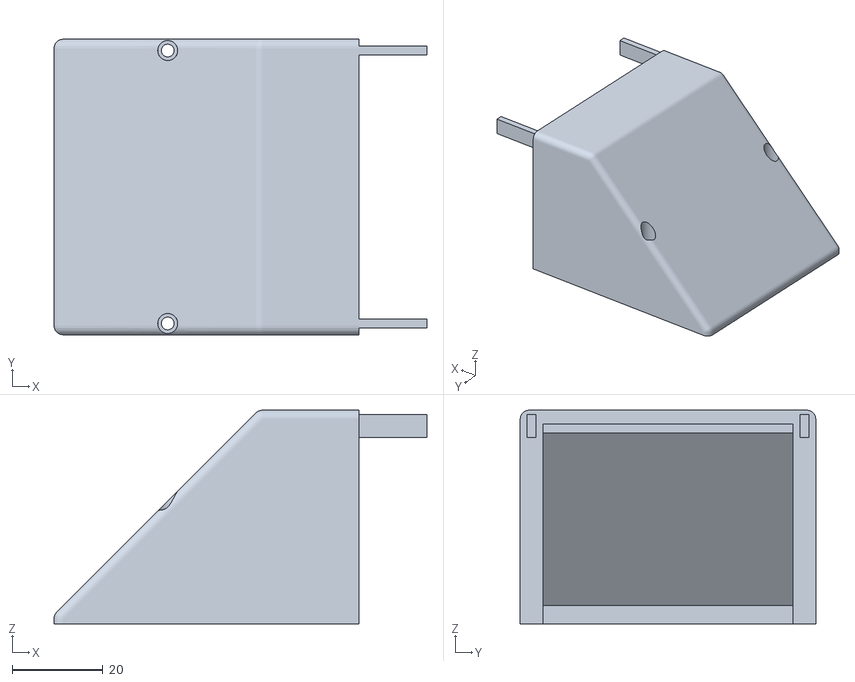
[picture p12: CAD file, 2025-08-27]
stl/coperchio sopra sinistra.stl
82.0 x 65.0 x 47.0

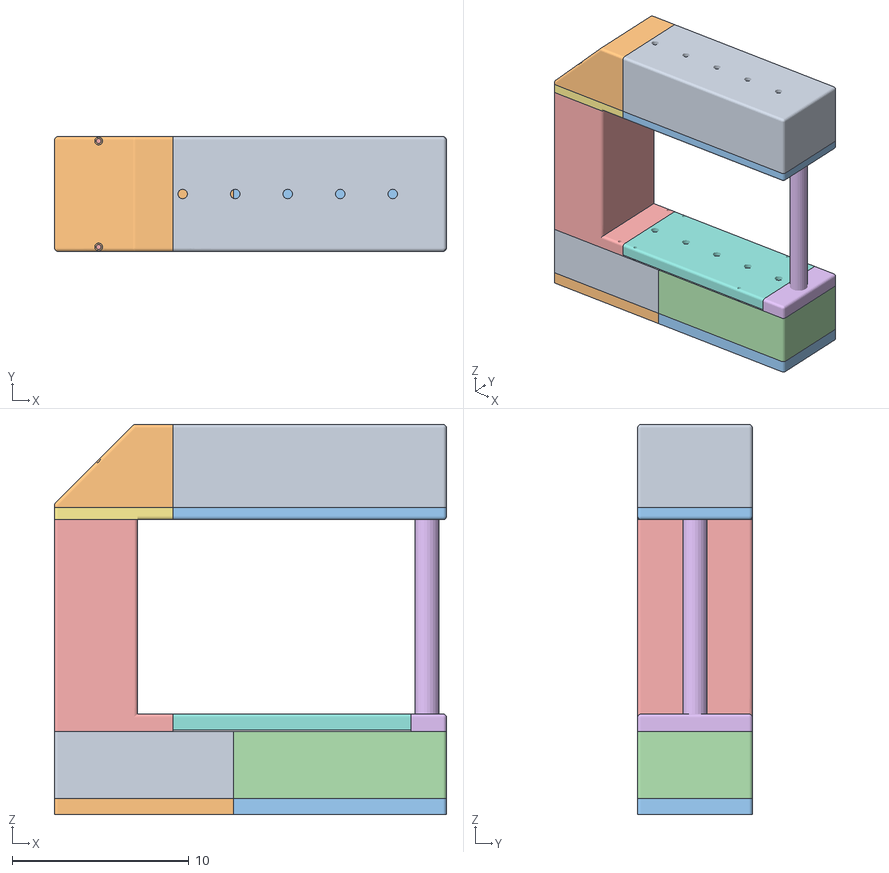
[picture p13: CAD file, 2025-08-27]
stl/laser-harp-model.obj
22.2 x 6.50 x 22.1
coperchio sinistra
base sinistra
base destra
coperchio destra
Corpo32
Corpo39
sopra sinistra
laser sopra
coperchio destra (1)
coperchio sinistra (1) (1) (1)
sopra destra

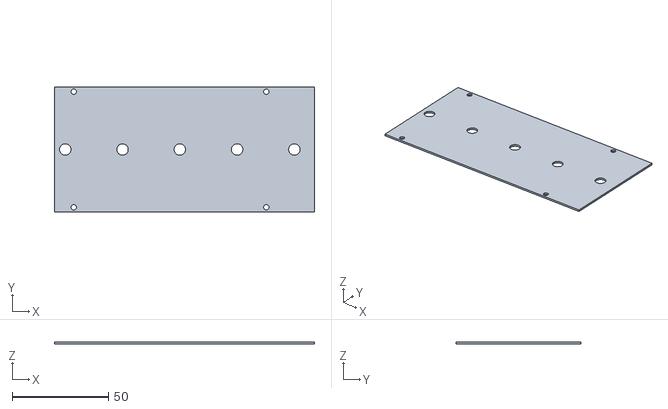
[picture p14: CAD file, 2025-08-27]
stl/laser sotto.stl
135.0 x 65.0 x 1.00

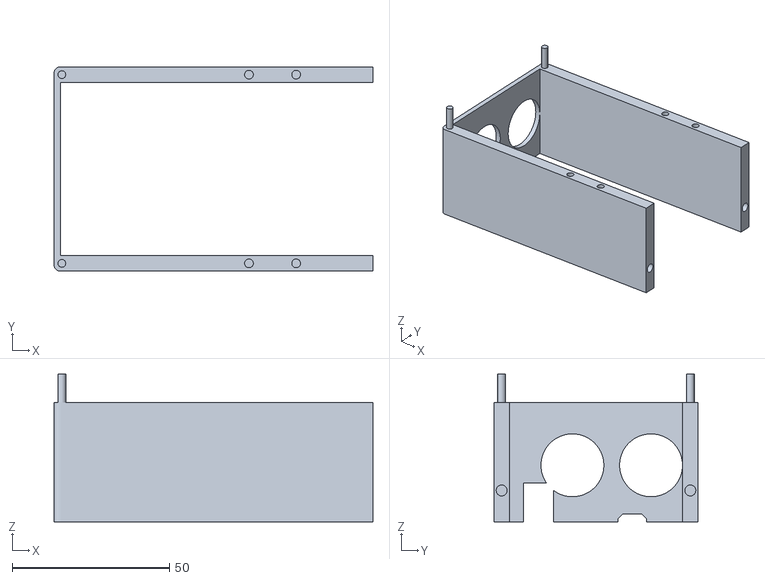
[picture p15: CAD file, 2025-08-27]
stl/coperchio sinistra.stl
101.4 x 65.0 x 47.0

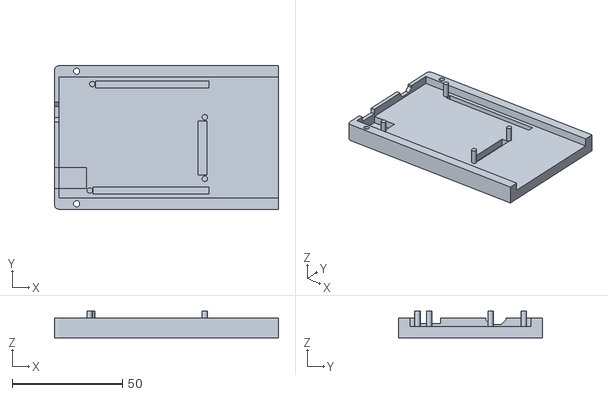
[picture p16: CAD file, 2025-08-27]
stl/base sinistra.stl
101.4 x 65.0 x 12.0

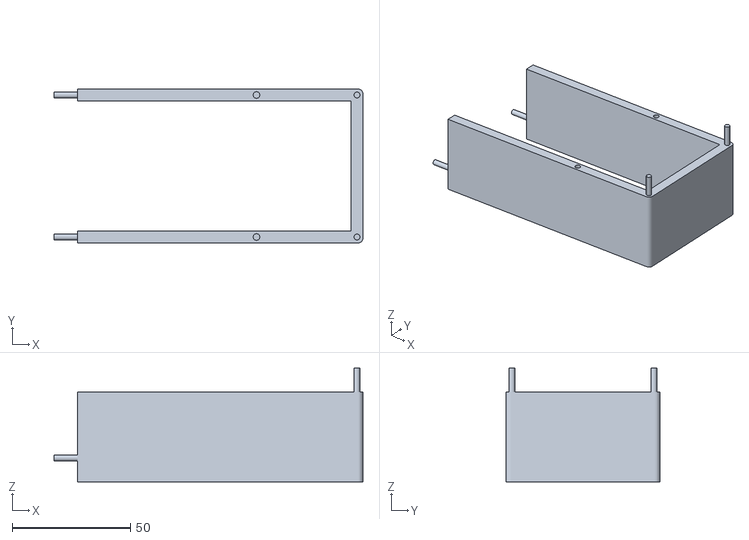
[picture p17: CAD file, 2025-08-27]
stl/coperchio destra.stl
130.6 x 65.0 x 48.0

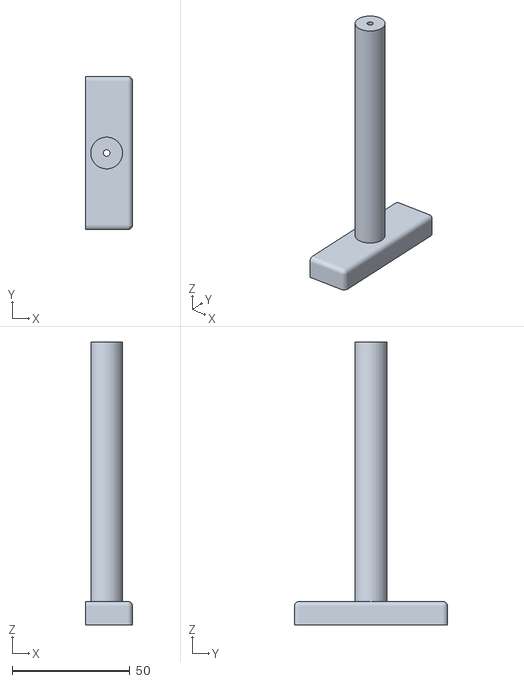
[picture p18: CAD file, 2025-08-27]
stl/colonna destra.stl
20.0 x 65.0 x 120.0

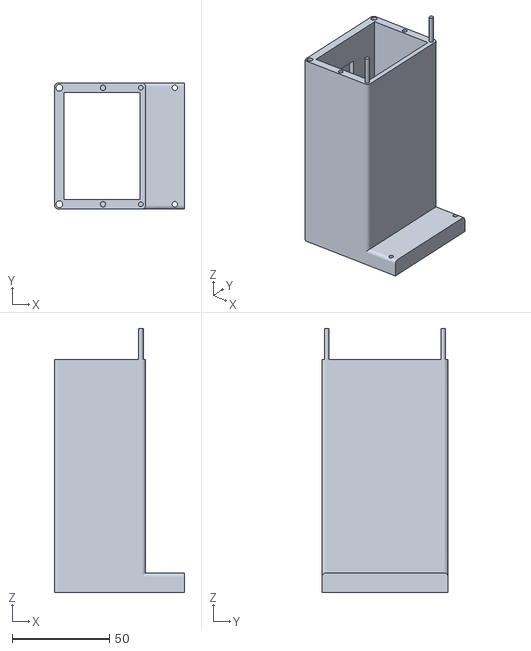
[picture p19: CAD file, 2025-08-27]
stl/colonna sinistra.stl
67.0 x 65.0 x 136.0

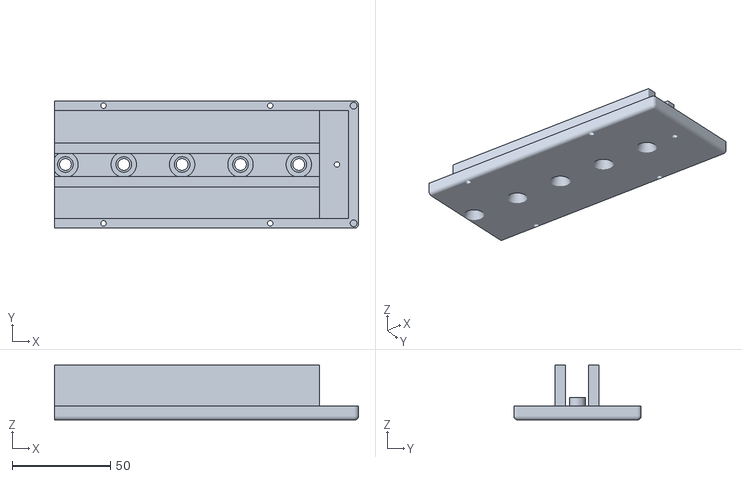
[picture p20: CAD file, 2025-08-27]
stl/sopra destra.stl
155.0 x 65.0 x 28.0

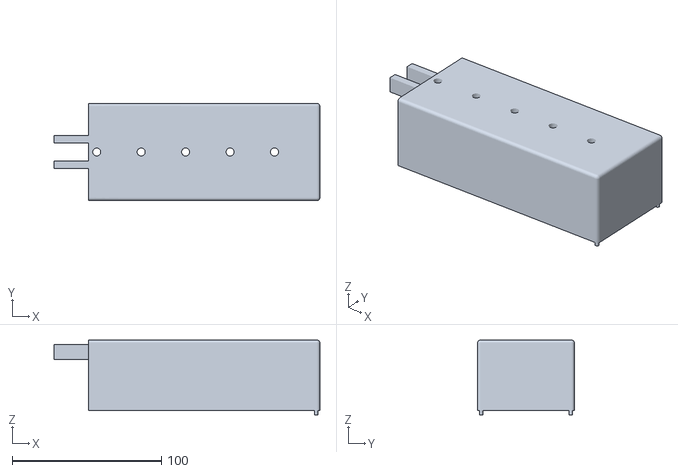
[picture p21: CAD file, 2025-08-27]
stl/coperchio sopra destra.stl
178.0 x 65.0 x 50.0

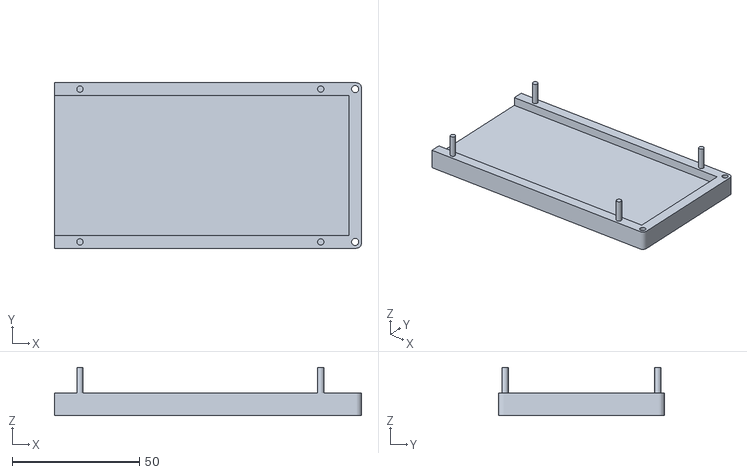
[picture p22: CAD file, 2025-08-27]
stl/base destra.stl
120.6 x 65.0 x 19.0

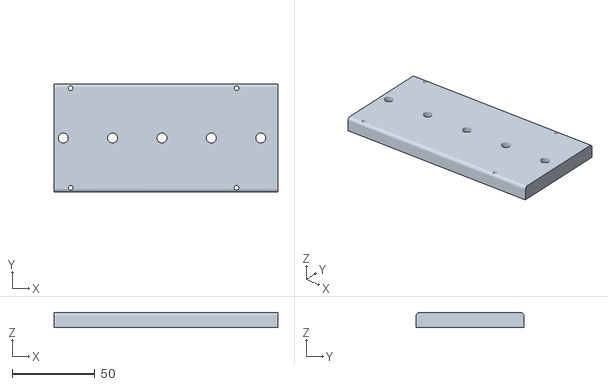
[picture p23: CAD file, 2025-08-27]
stl/laser sopra.stl
135.0 x 65.0 x 9.00

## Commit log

2025-08-22 Added arduino and controller scripts
2025-08-22 Added 3d models folder
    [base destra.stl, base sinistra.stl, colonna destra.stl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]
2025-09-02 Refactor and README
    [base destra.stl, base sinistra.stl, colonna destra.stl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]
